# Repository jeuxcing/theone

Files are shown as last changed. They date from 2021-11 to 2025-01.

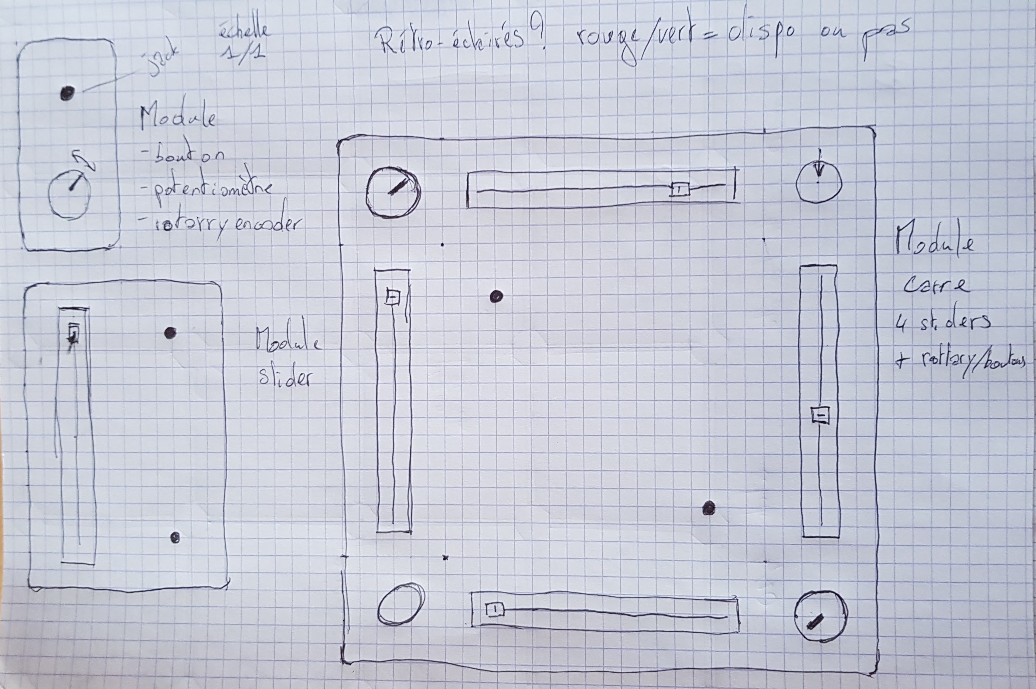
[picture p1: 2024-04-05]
doc/modules_console.jpg

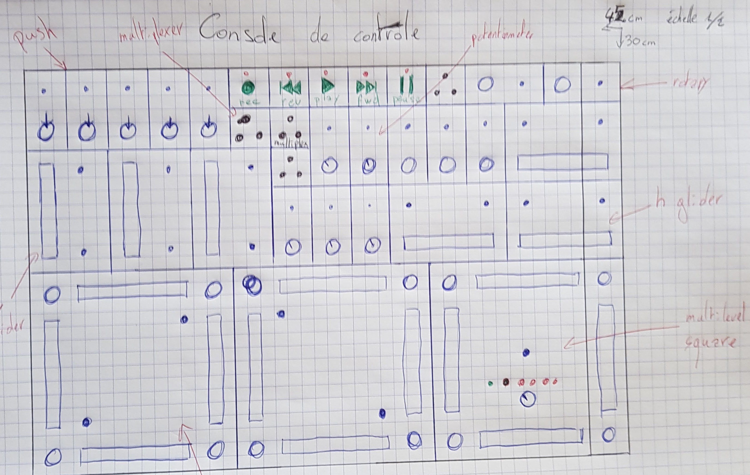
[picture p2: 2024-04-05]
doc/console_mixage.jpg

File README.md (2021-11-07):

# theone

One git to rule them all,  
   one git to find them,  
One git to bring them all  
   and in the darkness bind them.

As gently explained by the small poem, this git is now the main one and brings all the code from the others together.

## Directories

* blueprints: All the files needed to 3D print and laser cut the physical parts.
* game: Python core code for the game.
* gateway: Arduino code that transfer messages from/to serial to/from 1-wire.
* mix: Arduino codes to handle the mix table.
* wall: Arduino codes to handle the wall leds.

## Useful redirection

* Game message protocol is described in game/README.md
* 1-Wire message protocol is described in wall/README.md

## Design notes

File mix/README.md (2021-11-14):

# Mixer

## addresses (uint8_t)

* Main bus listener: 'M'
* Rotary encoders: 'R'
* Potentiometers: 'P'
* Vertical Linear Potentiometers 'V'
* Horizontal Linear Potentiometers 'H'
* Buttons: 'B'
* Control (Start/pause/...): 'C'

## Commands

### Link/Unlink (3 Bytes)

* Command Link/Unlink: 'L'/'U' (1 Byte)
* Object id: 0->7 (3 bits packed)
* Object type: ascii code (5 last bits)
* Wall coordinate: 0->25 (1 Byte)

# Wall

## Addresses (uint8_t)

* Main bus listener: 'M'
* Vertical addresser: 'V'
* Horizontal addresser: 'H'
* Rings addressers: 'R'

## Commands

### Declare link to the wall (4 Bytes)

* Serder type (see 1-Wire address for types) (1 Byte)
* Link command 'L' (1 Byte)
* Mixer coordinate (1 Byte)
* Wall coordinate (1 Byte)

### Break link to the wall (4 Bytes)

* Serder type (see 1-Wire address for types) (1 Byte)
* Unlink command 'U' (1 Byte)
* Mixer coordinate (1 Byte)
* Wall coordinate (1 Byte)

### Send controler value (4 Bytes)

* Serder type (see 1-Wire address for types) (1 Byte)
* Value command 'V' (1 Byte)
if rotary type, 32 for "-1", 64 for "+1"
* Mixer coordinate (1 Byte)
* Value (1 Byte)

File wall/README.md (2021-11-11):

# Content Summary

## lines_controler

Connect to n led strips lines (vertical horizontal or rings is only one define change at the beginning of the file).
Receive commands from the 1-wire PJON network and show them on the strip.
See Lines protocol for network commands.

# 1-Wire protocol

## Color 1 led

Set 1 led to a RGB value.

6 Bytes:
* Command: 'L' char (1 Byte)
* Line coordinate (1 Byte)
* Led coordinate (1 Byte)
* Colors \[R, G, B\] (3 Bytes)

## Color 1 segment

Set 1 color in between two pixels (included)

7 Bytes:
* Command: 'S' char (1 Byte)
* Line coordinate (1 Byte)
* Start led coordinate (1 Byte)
* Stop led coordinate (1 Byte)
* Colors \[R, G, B\] (3 Bytes)

## Multi-packet (3 + ... Bytes)

* Command: 'M' (1 Byte)
* Number of encapsulated packets: 0 to 255 (1 Byte)
* Content: Concatenated packets (Variable size)

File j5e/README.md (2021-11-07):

# j5e

Python engine for jeuxcinq

# Grid protocol

## Light 1 Led \[8 Byte\]

* Command: 'L' \[1 Byte\]
* Strip: 'V' (vertical) or 'H' (horizontal) or 'R' (ring) \[1 Byte\]
* Segment coordinates: line (0 -> 4) \[1 Byte\], segment (0 -> 3) \[1 Byte\]
* Led: (0 -> 23 or 11) \[1 Byte\]
* Color RGB \[3 Byte\] 

## Light wall segment \[9 Byte\]

* Command: 'S' \[1 Byte\]
* Strip: 'V' (vertical) or 'H' (horizontal) or 'R' (ring) \[1 Byte\]
* Start segment coordinates : line (0 -> 4) \[1 Byte\], segment (0 -> 3) \[1 Byte\]
* Start/stop leds: (0 -> 23 or 11) * 2 \[2 Byte\]
* Color RGB \[3 Byte\]

## Multi-packet \[3 + ... Bytes\]

* Command: 'M' \[1 Byte\]
* Destination: Id of the arduino to reach on the 1-Wire \[1 Byte\]
* Number of encapsulated packets: 0 to 255 \[1 Byte\]
* Content: Concatenated packets \[Variable size\]

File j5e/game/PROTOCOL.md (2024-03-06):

Toutes les interactions réseau qui modifient l'état du jeu

play : Démarre le temps dans un niveau
pause : Stop le temps
reset : Redémarrer le niveau

rotation <row> <col> : Changement de sens de rotation d'un anneau à la coordonnée row col.

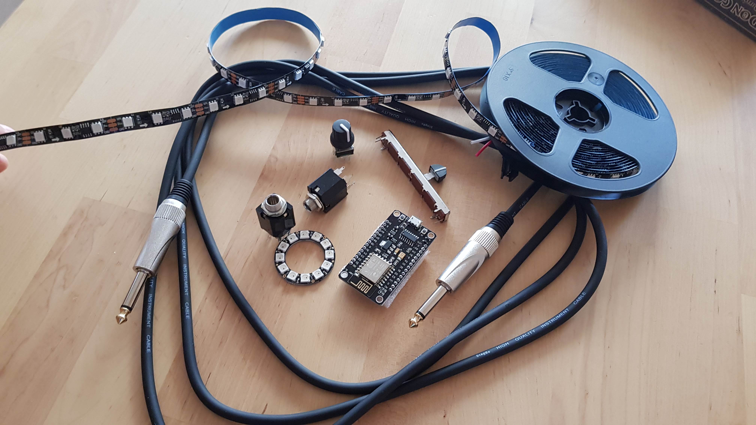
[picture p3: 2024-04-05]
doc/matériel.jpg

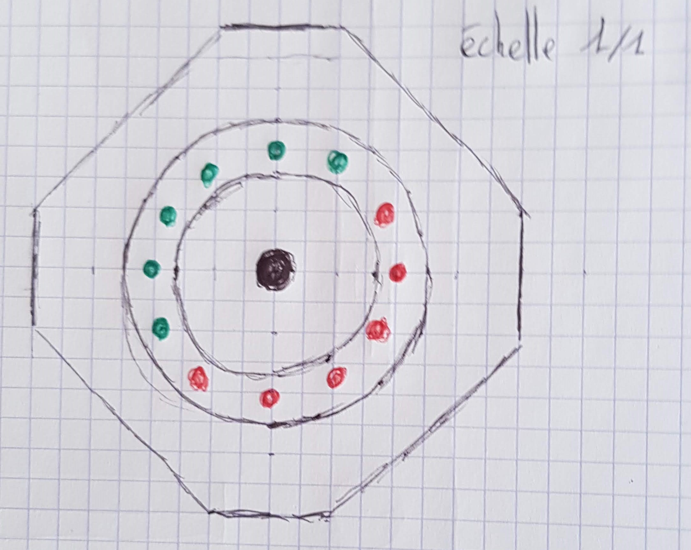
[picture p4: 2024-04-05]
doc/croisement_mur.jpg

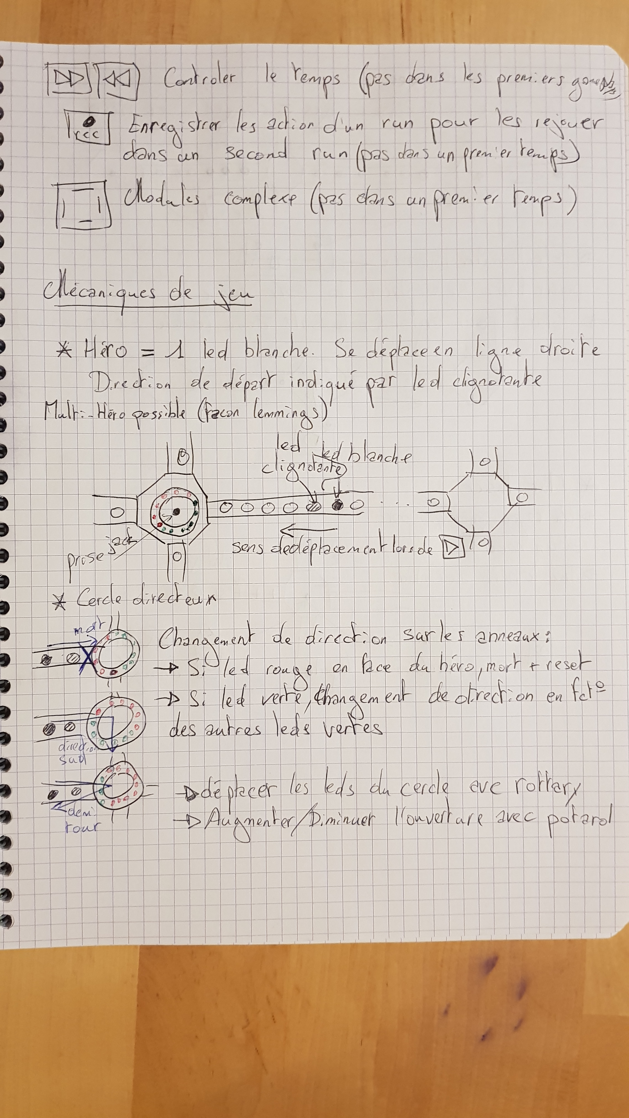
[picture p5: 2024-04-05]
doc/runner 2.jpg

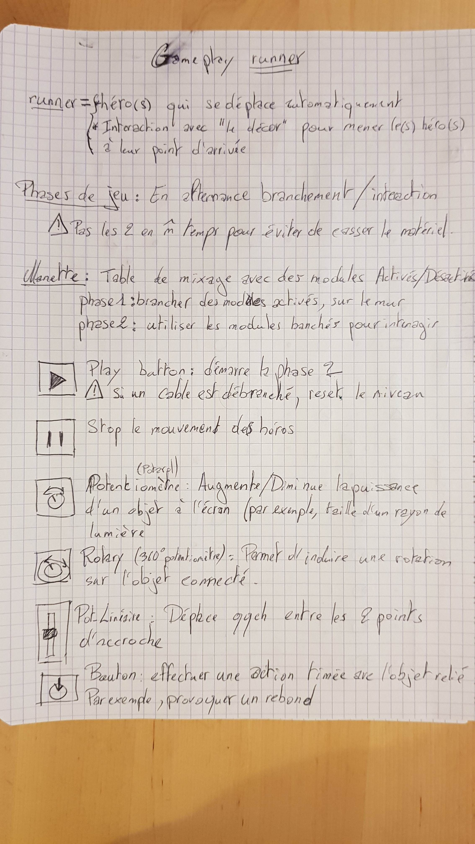
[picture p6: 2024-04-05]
doc/runner 1.jpg

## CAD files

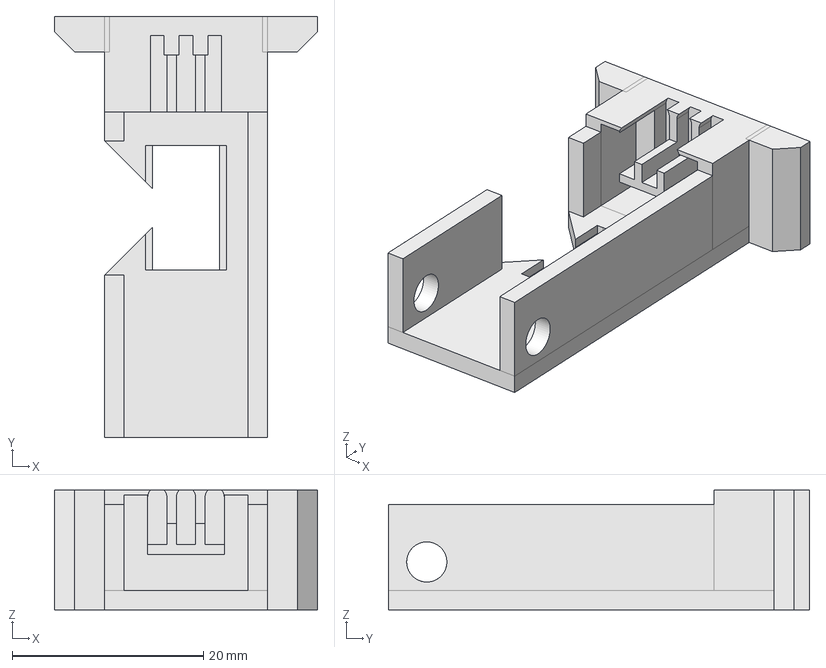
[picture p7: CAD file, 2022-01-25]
blueprints/wall/3D_models/connector_8_wires.FCStd
27.5 x 44.0 x 12.5 mm

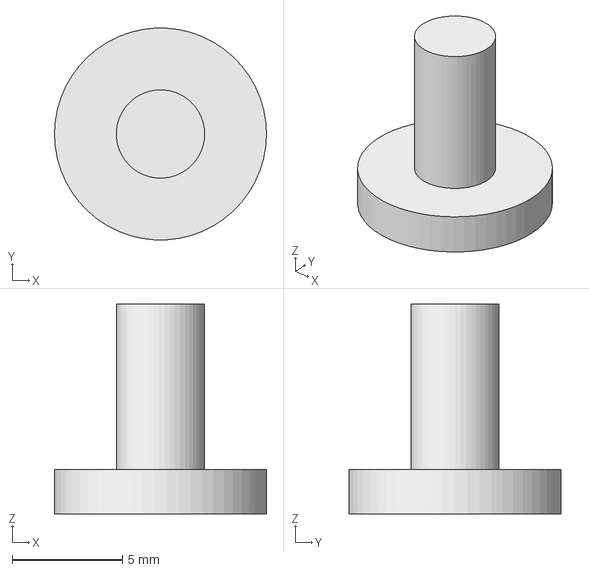
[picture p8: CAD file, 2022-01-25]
blueprints/wall/3D_models/connector_hook_clip.FCStd
9.60 x 9.58 x 9.50 mm

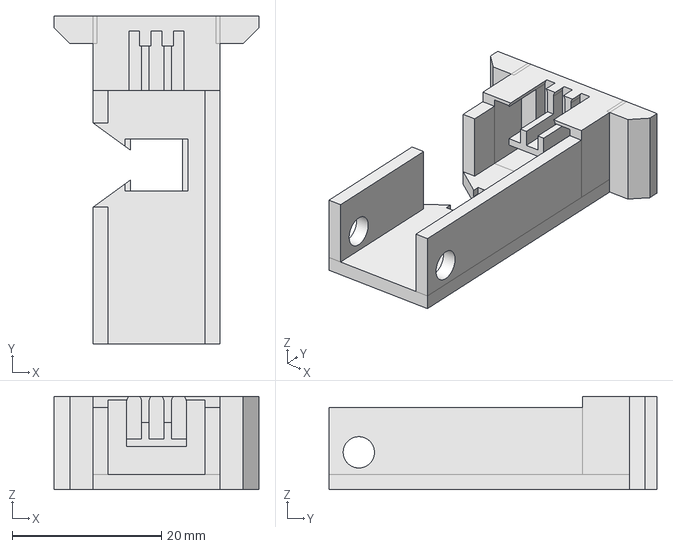
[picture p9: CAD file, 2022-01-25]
blueprints/wall/3D_models/connector_4_wires.FCStd
27.5 x 44.0 x 12.5 mm

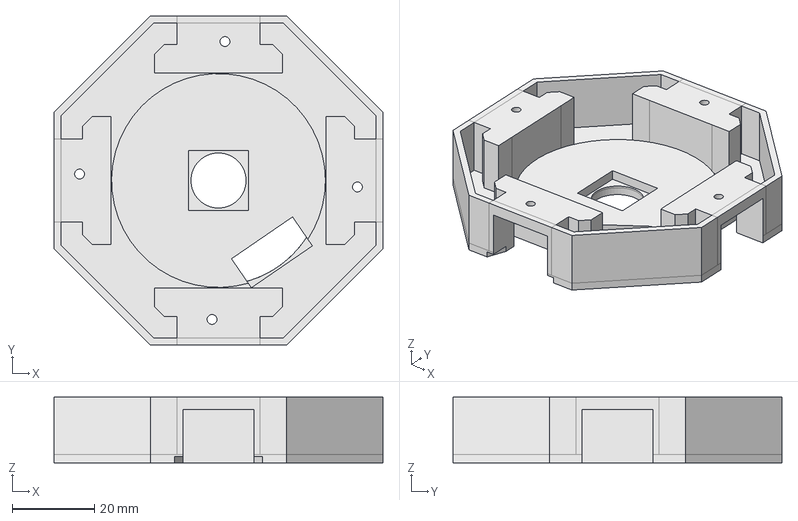
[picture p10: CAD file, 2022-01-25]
blueprints/wall/3D_models/box_lid.FCStd
80.0 x 80.0 x 16.0 mm

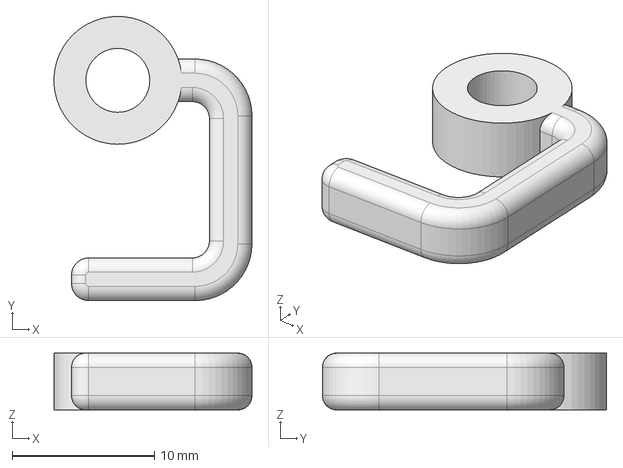
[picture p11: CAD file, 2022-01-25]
blueprints/wall/3D_models/connector_hook.FCStd
13.9 x 20.0 x 4.00 mm

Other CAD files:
blueprints/wall/3D_models/box_lid.stl
blueprints/wall/3D_models/connector_4_wires.stl
blueprints/wall/3D_models/connector_8_wires.stl
blueprints/wall/3D_models/connector_hook.stl
blueprints/wall/3D_models/connector_hook_clip.stl

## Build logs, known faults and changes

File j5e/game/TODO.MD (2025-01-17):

# NOTICE
Pour lancer : 
le jeu :
python3 -m j5e.game
le controleur :
python3 -m j5e.game.panelAdmin

un serveur web simple :
python3 -m http.server 8080

Commandes réseau d'interaction avec le jeu : j5e/game/PROTOCOL.md

Pour quitter proprement, play après le Game Over

Pour gagner un niveau, il faut que le nombre de lemmings requis total soit atteint

# INPROGRESS

- Mise à jour de l'état des lemmings lors du play. 
Pour l'instant on voit les cases se colorer lors du premier déplacement.

# TODO
- Bug: Horloge set_color 12 ne fonctionne pas
- On affiche pas le bon pixel lors d'un déplacement sur un anneau.
- Ajouter l'effacement des traces
- refacto from_coord_content / from_coord (DRY)
- modéliser les événements (état d'un élément du jeu / actions qui démarrent ou s'arrêtent)
-> le contrôleur (ESP) préempte l'évolution de l'état de sa vue associée mais c'est le moteur de jeu qui reste chef d'orchestre et resynchronise au besoin
- en pause, tout est synchronisé
- play -> on décentralise mouvements et collisions

- ajouter la possibilité de lancer un niveau choisi (bouton charger niveau + field numéro)

- faire le js de la rotation
- sérialization des éléments du level

- modélisation des actions de jeu

- Classe timée qui envoie les commandes
- Plug on/off

- intégrer l'envoi du niveau sérialisé à chaque début de niveau, msg = load_lvl ???

- ajouter des items de gameplay
    - aiguillage
    - lave leminningicide roundupisante
    - déplaceur d'objet
    - tapis roulant (fixe à une case)
    - case active / inactive

- faire le controleur
    - déplacement d'élément par
        - l'activation du potentiomètre linéaire 
        - l'activation du rotary encoder

- créer une structure du jeu complet

- interface de création de niveau en js

- aller plus loin dans le chargement des data json en objets pythons de nos classes..?
https://pynative.com/python-convert-json-data-into-custom-python-object/

# DONE 

- AdminFlask SSE : mettre en place une Queue par client (sinon un seul reçoit)

- capturer le control C pour quitter proprement (pb de port sinon)

- suppression des teleporters et lemmings dans json si vide

- dans Level, tout mettre dans agents en se passant de lemings et generators

- sérialisation des exits

ngs dans level
    - récupération des éléments modifiés
        - gestion des éléments sur un level (Map <coordonnée, element>)
            - appels de add element lors des ajouts de lemmings dans level
            - méthode de suppression des éléments dans level
- méthode de suppression des éléments dans level# DONE

- sockets non bloquants
- commande reset de niveau
- gagner le niveau
- générateur de lemmings
- Simuler les entrées de commande
    - Fausse interaction réseau
        - Centre de commande qui modifie l'état du jeu
- niveau 3 carré rotation 0 1 victorieuse
- commande rotation row col
- noter dans un fichier le protocole
- commande play : lancer niveau côté controller
- Supprimer résidu RingState
- Terminal interactif (play / pause)
- segment actif / inactif
- lemmings bougent correctement
- lemmings disparaissent une fois la sortie passée
- téléporteur
- nettoyage du GameEngine
- séparation Level / LevelBuilder
- 1er refacto LevelBuilder
- refacto Agent/Element
- transformer en package python
- plusieurs chemins de levels dans un fichier
- plusieurs levels dans le jeu
- alléger try parsing json dans LevelBuilder
- Thread de contrôle via socket
- Stop
- Play

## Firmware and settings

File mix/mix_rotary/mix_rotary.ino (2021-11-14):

//#define SWBB_MODE 4
#include <PJONSoftwareBitBang.h>

//#define TYPE 'R' /* Rotary /**/
#define TYPE 'P' /* Potard /**/
//#define TYPE 'L' /* Linear /**/
//#define TYPE 'B' /* Button /**/
//#define TYPE 'H' /* Horizontal Slider /**/
//#define TYPE 'V' /* Vertical Slider /**/

#if TYPE =='V' or TYPE =='H'
  #define NB_JACKS 4 //shall be 6 later
#else
  #define NB_JACKS 5
#endif

#define NET_PIN 2
#define DISCONNECT_DELAY 500

unsigned int plug_pins[] = {3, 5, 7, 9, 11};
bool plugged[] = {false, false, false, false, false};
unsigned int network_pins[] = {4, 6, 8, 10, 12};
uint8_t pairs[] = {255, 255, 255, 255, 255};
unsigned long last_contact[] = {0, 0, 0, 0, 0};
unsigned int measure_pins[] = {A0, A1, A2, A3, A4};
unsigned int measure_pinsB[] = {A3, A4, A5}; //For the rotary, baby

uint16_t values[] = {0, 0, 0, 0, 0};

int rotatyState[5] = {0, 0, 0, 0, 0};
unsigned long rotaryFirstTime[5] ={0, 0, 0, 0, 0};
int averageRotary[5]= {0, 0, 0, 0, 0};
bool rotaryWaiting[5]= {false, false, false, false, false};

int current_pin = 100;

PJONSoftwareBitBang jack_bus;
PJONSoftwareBitBang main_bus;

uint8_t jack_coordinate(int pin){
  if ((TYPE == 'V') or (TYPE=='H')){
    uint8_t pos,num;
    pos = pin%2<<4;
    num = int(pin/2); 
    return pos | num;
  } else{
    return pin;
  }
}

void print_coordinate(int pin){
  if ((TYPE == 'V') or (TYPE == 'H')){
      Serial.print(TYPE);
      Serial.print(pin%2);
      Serial.print('N');
      Serial.print(int(pin/2));
    }
    else{
      Serial.print(pin);
    }
}

void jack_receiver(uint8_t *payload, uint16_t length, const PJON_Packet_Info &info) {
  if (pairs[current_pin] != *payload) {
    print_coordinate(current_pin);
    Serial.print(" <---> ");
    Serial.println(*payload);

    // Send the connection
    uint8_t packet[3];
    // Link command
    packet[0] = 'L';
    // Wich part of the controller
    packet[1] = TYPE & 0b00011111;
    packet[1] |= jack_coordinate(current_pin) << 5;
    packet[2] = *payload;
    Serial.print(packet[0]);Serial.print(" ");
    Serial.print(packet[1]);Serial.print(" ");
    Serial.print(packet[2]);Serial.println();
    main_bus.send_packet_blocking('M', packet, 3);
  }
  // Register pair
  pairs[current_pin] = *payload;
  last_contact[current_pin] = millis();
}

int detectRotation(int pin1, int pin2,int *lastEncoded){
  int MSB = digitalRead(pin1);
  int LSB = digitalRead(pin2); 
  int result = 0;
  int encoded = (MSB << 1) |LSB; 

  int sum = (*lastEncoded << 2) | encoded;
  (*lastEncoded) = encoded; 

  if(sum == 0b1101 || sum == 0b0100 || sum == 0b0010 || sum == 0b1011) {
    result++;
  }
  if(sum == 0b1110 || sum == 0b0111 || sum == 0b0001 || sum == 0b1000){
    result--;
  }

  if(result > 0){
    return 64; //Turn Right
  }else if(result < 0){
    return 128; //Turn Left
  }
  else{
    return 255;//No rotation
  }
}
  
void setup() {
  Serial.begin(115200);

  // Set jack plug readers
  for (int i=0 ; i<NB_JACKS ; i++) {
    pinMode(plug_pins[i], INPUT_PULLUP);  
  }
  
  for (int i=0 ; i<3 ; i++){
    pinMode(measure_pins[i],INPUT_PULLUP);
    if (TYPE == 'R')
      pinMode(measure_pinsB[i],INPUT_PULLUP);
  }

  // Set Jack BitBang bus
  jack_bus.strategy.set_pin(network_pins[0]);
  jack_bus.set_id(100);
  jack_bus.begin();
  jack_bus.set_receiver(jack_receiver);


  // Set 
  main_bus.strategy.set_pin(NET_PIN);
  main_bus.set_id(TYPE);
  main_bus.begin();

}


void loop() {
  for (int i=0 ; i<NB_JACKS ; i++) {
    bool to_disconnect = false;
    
    bool prev = plugged[i];
    plugged[i] = (digitalRead(plug_pins[i]) == LOW);
    if (prev and not plugged[i] and pairs[i] != 255) {
      to_disconnect = true;
    }

    // Pair jack check
    if (plugged[i] == true) {
      jack_bus.strategy.set_pin(network_pins[i]);
      current_pin = i;
      uint16_t result = jack_bus.receive(50);

      // Check distant jack status and trigger disconnection
      if (pairs[i] != 255 and millis() - last_contact[i] > DISCONNECT_DELAY) {
        to_disconnect = true;
      }
      // Read the value if connected
      else if (pairs[i] != 255) {
        uint8_t value = 255;
        switch (TYPE) {
          case 'V':
            if((i%2==1) and (plugged[i-1] == true) and (pairs[i]%5 == pairs[i-1]%5)){
              value = analogRead(measure_pins[int((i-1)/2)]) / 4;
            }
            break;
          case 'H':
            if((i%2==1) and (plugged[i-1] == true) and (pairs[i]/5 == pairs[i-1]/5)){
              value = analogRead(measure_pins[int((i-1)/2)]) / 4;
            }
            break;
          case 'P':
            value = analogRead(measure_pins[i]) / 4;
            break;
          case 'B':
            value = digitalRead(measure_pins[i]) == LOW ? 254 : 0;
            break;
          case 'R':
            unsigned long currentTime = millis();
            int currentValue = detectRotation(measure_pins[i], measure_pinsB[i],&rotatyState[i]); 
            if(currentValue == 255 && currentTime > rotaryFirstTime[i] + 200 && rotaryWaiting[i]){
              if(averageRotary[i] >=96 ){
                value= 128;
              }else{
                value = 64;
              }
              rotaryWaiting[i] = false;
            }

            if(currentValue != 255){
              if(currentTime > rotaryFirstTime[i] + 200){
                rotaryFirstTime[i] = currentTime;
                averageRotary[i] = currentValue;
                rotaryWaiting[i] = true;
              }else{
                averageRotary[i] = (averageRotary[i] + currentValue) / 2;
              }
            }
          
            break;
        }

        if ((value!=255) and ((abs(((int16_t)value) - ((int16_t)values[i])) > 3) or (TYPE=='R'))) {
          values[i] = value;

          uint8_t packet[3];
          // Value command
          packet[0] = 'V';
          // Wich part of the controller
          packet[1] = TYPE & 0b00011111;
          packet[1] |= jack_coordinate(i) << 5;
          // Value
          packet[2] = value;
          main_bus.send_packet_blocking('M', packet, 3);

          Serial.println(TYPE);
          Serial.println(jack_coordinate(i));
          Serial.println(value);
          Serial.print(packet[0]);Serial.print(" ");
          Serial.print(packet[1]);Serial.print(" ");
          Serial.print(packet[2]);Serial.println();
          Serial.print(TYPE);
          Serial.print(" [");
          print_coordinate(i);
          Serial.print("]: ");
          Serial.println(value);
        }
      }
    }

    // Send disconnection info
    if (to_disconnect) {
      unsigned int packet[4];
      packet[0] = 'U';
      // Wich part of the controller
      packet[1] = TYPE & 0b00011111;
      packet[1] |= jack_coordinate(current_pin) << 5;
      // Link coordinates
      packet[2] = pairs[i];
      main_bus.send_packet_blocking('M', packet, 3);

      print_coordinate(i);
      Serial.print("   X   ");
      Serial.println(pairs[i]);

      // Locally register the disconnection
      pairs[i] = 255;
    }
  }
}

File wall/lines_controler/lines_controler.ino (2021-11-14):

//#define SWBB_MODE 4
#include <PJONSoftwareBitBang.h>
#define FASTLED_INTERNAL
#include <FastLED.h>


// --- Change here to define the led strip type ---

// #define NET_ID 'R' /* Rings */
#define NET_ID 'V' /* Columns */
// #define NET_ID 'H' /* Rows */

// ------------------------------------------------


#define REFRESH_DELAY 5
#define NB_LINES 3

#if NET_ID == 'R'
  #define NB_SEGMENTS 5
  #define NB_LED_SEGMENT (12)
#else
  #define NB_SEGMENTS 4
  #define NB_LED_SEGMENT (24)
#endif

#define NB_LEDS_LINE (NB_SEGMENTS * NB_LED_SEGMENT)


//int pins[5] = {2, 3, 5, 6, 7};
#define PIN0 2
#define PIN1 3
#define PIN2 5
#define PIN3 6
#define PIN4 7

CRGB lines[NB_LINES][NB_LEDS_LINE];

#define NET 12
PJONSoftwareBitBang bus;


bool modified[NB_LINES];


void modify_led(uint8_t * payload, uint8_t length) {
  uint8_t line_idx = payload[1];
  uint8_t led_idx = payload[2];
  uint8_t red = payload[3];
  uint8_t green = payload[4];
  uint8_t blue = payload[5];

  Serial.print(line_idx);Serial.print(",");
  Serial.print(led_idx);Serial.print(" ");
  Serial.print(red);Serial.print(" ");
  Serial.print(green);Serial.print(" ");
  Serial.print(blue);Serial.println();
  lines[line_idx][led_idx].setRGB(red, green, blue);
  modified[line_idx] = true;
}


void modify_segment(uint8_t * payload, uint8_t length) {
  uint8_t line_idx = payload[1];
  uint8_t start_led_idx = payload[2];
  uint8_t stop_led_idx = payload[3];
  uint8_t red = payload[4];
  uint8_t green = payload[5];
  uint8_t blue = payload[6];

  for (uint8_t i=start_led_idx ; i<= stop_led_idx ; i++) {
    lines[line_idx][i].setRGB(red, green, blue);
  }
  modified[line_idx] = true;
}


void receiver_function(uint8_t * payload, uint16_t length, const PJON_Packet_Info &info) {
  //Serial.println("Packet received");

  int remaining_msgs = 1;

  while (remaining_msgs > 0) {
    uint8_t command = payload[0];
    switch(command) {
      case 'L':
        modify_led(payload, length);
        break;
      case 'S':
        modify_segment(payload, length);
        break;
      case 'M':
        remaining_msgs = payload[1] + 1;
        length = 2;
        break;
    }
    
    remaining_msgs--;
    payload += length;
    length = payload[0];
    payload += 1;
  }
};


void setup() {
  // Init led strips
  FastLED.addLeds<NEOPIXEL, PIN0>(lines[0], NB_LEDS_LINE);
  FastLED.addLeds<NEOPIXEL, PIN1>(lines[1], NB_LEDS_LINE);
  FastLED.addLeds<NEOPIXEL, PIN2>(lines[2], NB_LEDS_LINE);
  FastLED.addLeds<NEOPIXEL, PIN3>(lines[3], NB_LEDS_LINE);
  FastLED.addLeds<NEOPIXEL, PIN4>(lines[4], NB_LEDS_LINE);

  // Init network
  // Set the pin 12 as the communication pin
  bus.strategy.set_pin(NET);
  bus.set_id(NET_ID);
  
  // Define network callback
  bus.set_receiver(receiver_function);

  Serial.begin(115200);
}

unsigned long previous_show = 0;

void loop() {
  for (int i=0 ; i<10 ; i++)
    bus.receive();

  unsigned long current_time = millis();
  if (current_time - previous_show > REFRESH_DELAY) {
    for (int line_idx=0 ; line_idx<NB_LINES ; line_idx++) {
      if (modified[line_idx]) {
        FastLED.show();
        modified[line_idx] = false;
      }
    }
    previous_show = millis();
  }
}

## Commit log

2021-11-07 all arduino codes
2021-11-07 connexion laser cuts
2021-11-11 condtions linéarités sur les jacks des sliders
2021-11-11 résolution pb de paquetages
2021-11-11 des tests :O !
2021-11-11 models 3D and svg for the box
    [couvercle - V2 - novembre.FCStd, couvercle - V2 - novembre.stl]
2021-11-11 la passe !
2021-11-12 poc utilisation rotary encoder
2021-11-12 mise a jour de mix_rotary
2021-11-13 led wall ok
2021-11-14 début de chargement d'agent + ajout niveau démo basique et son test
2022-01-25 wall's blueprint working protoype - update and cleanning
    [box_lid.FCStd, box_lid.stl, connector_4_wires.FCStd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]
2023-07-21 game engine refactoring:no more graph, coordinate system, timer internal
2024-02-02 :construction:Commande de changement de sens de rotation dans les rings
2024-02-14 :bug: loop sur le défaite + :construction: générateur de lemmings
2024-03-06 :white_check_mark: generateur de lemmings ok
2024-04-10 :construction: server http qui sert des fichiers ou des services
2024-05-09 :construction: l'enfer du socket
2024-05-28 :thread: Régler les problème de socket bloquants lors des ctrl+c
2024-07-05 :thread: socket reuse
2024-07-05 :art: ajout d'éléments pour modifier la vue en direct
2024-07-10 :sparkles: Socket dans les deux sens qui fonctionnent
2024-07-10 :construction: Serialisation du niveau pour envoie à la vue
2024-07-15 :recycle: vidange de la tete de delco
2024-07-16 :thread: Réparation de tous les sockets + threads de l'application. Ctrl+C ok
2024-07-16 serialization : des trucs
2024-07-17 :thread: Oh qu'est-ce que j'en ai chié
2024-08-28 :thread: SSE ok for multiple client connections
2024-11-06 :construction: Automatisation de la mise à jour du status de la grille
2024-12-13 :bug: Parsing de & déclenche un bug
2025-01-17 :bug: fix bug du main. :recycle: Nettoyage de l'arborescence
2025-01-17 :construction: Les lemmings laissent des traces
